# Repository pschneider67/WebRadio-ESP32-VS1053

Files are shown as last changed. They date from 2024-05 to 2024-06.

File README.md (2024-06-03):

Here I show the hardware of a small Internet radio consisting of: 
- ESP32 
- VS1053b 
- 2.2" TFT display
- Amplifier module PAM8403

The boards were created with KiCad version 8.

grafik

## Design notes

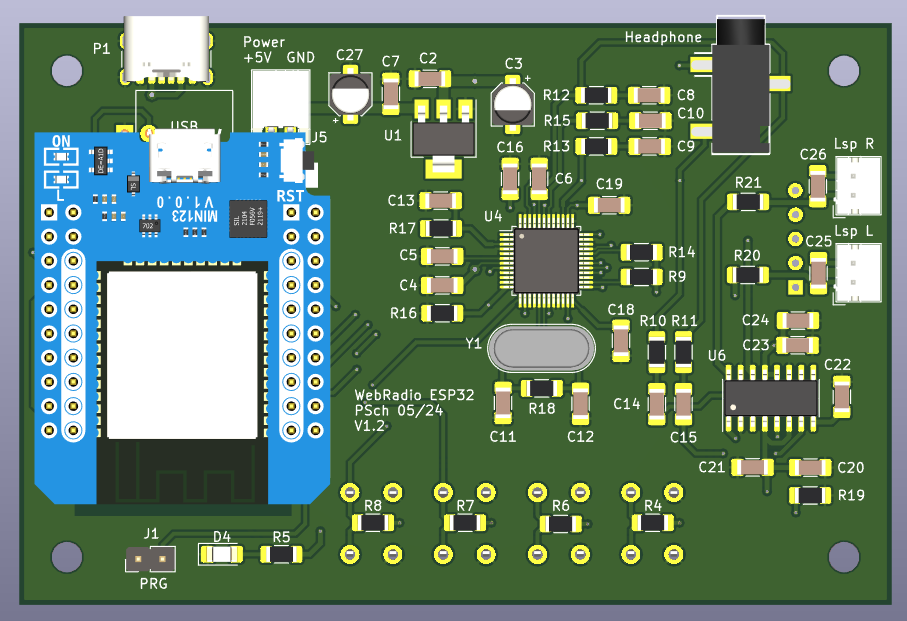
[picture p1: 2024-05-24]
WebRadio.png

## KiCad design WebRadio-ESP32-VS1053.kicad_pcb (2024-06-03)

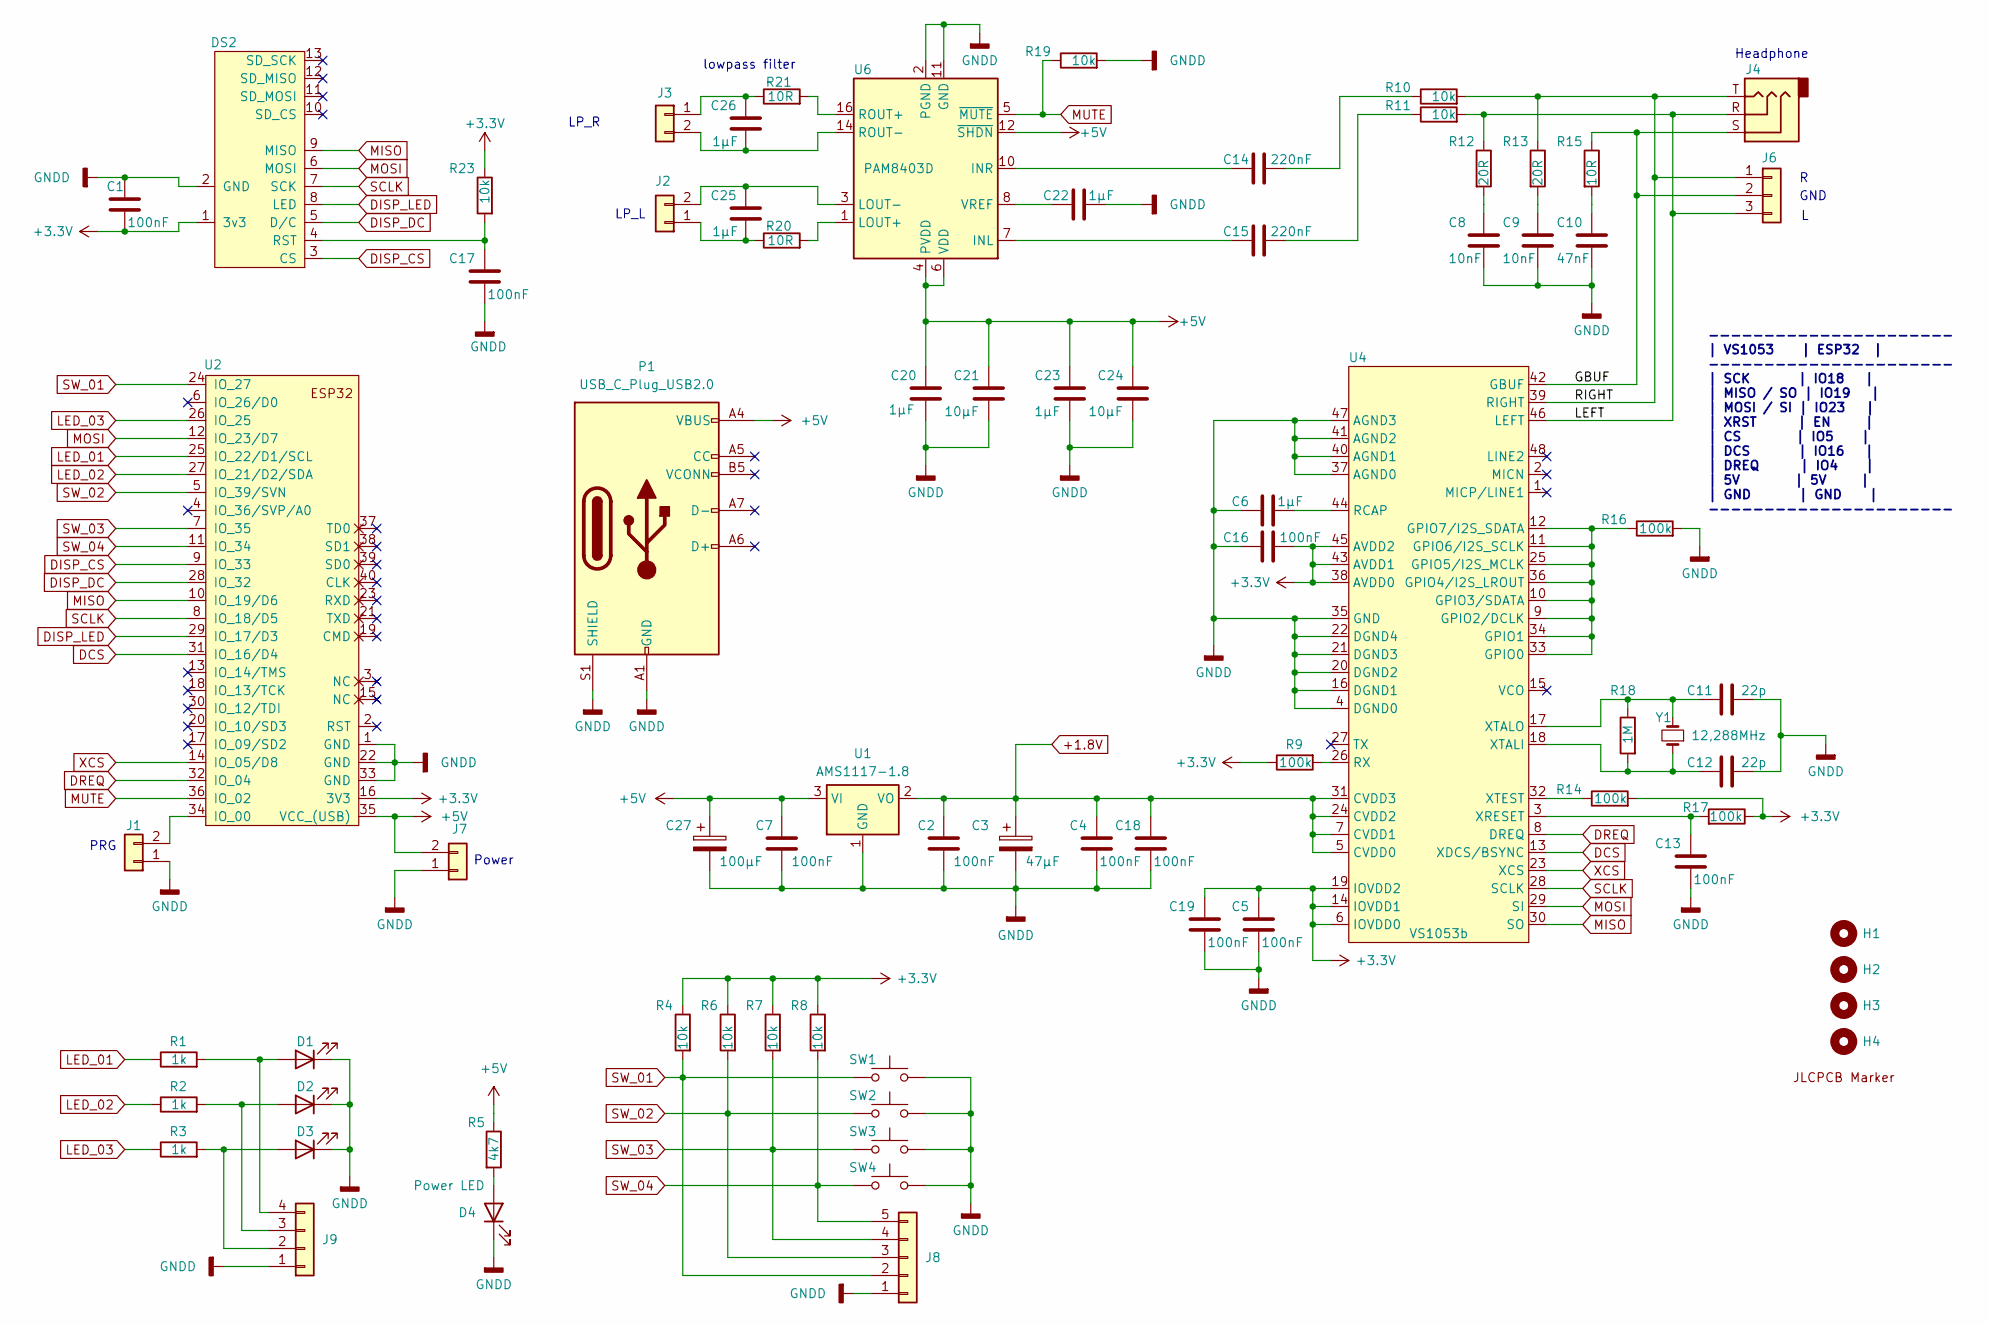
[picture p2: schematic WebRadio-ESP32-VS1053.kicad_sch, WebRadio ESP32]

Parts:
C1, C2, C4, C5, C7, C13, C16, C17, C18, C19: 100nF; C_1206_3216Metric_Pad1.33x1.80mm_HandSolder
C3: 47µF; CP_Elec_5x5.4
C6, C20, C22, C23, C25, C26: 1µF; C_1206_3216Metric_Pad1.33x1.80mm_HandSolder
C8, C9: 10nF; C_1206_3216Metric_Pad1.33x1.80mm_HandSolder
C10: 47nF; C_1206_3216Metric_Pad1.33x1.80mm_HandSolder
C11, C12: 22p; C_1206_3216Metric_Pad1.33x1.80mm_HandSolder
C14, C15: 220nF; C_1206_3216Metric_Pad1.33x1.80mm_HandSolder
C21, C24: 10µF; C_1206_3216Metric_Pad1.33x1.80mm_HandSolder
C27: 100µF; CP_Elec_5x5.4
D1, D2, D3: Power LED; LED_D3.0mm_SMD
D4: Power LED; LED_1206_3216Metric_Pad1.42x1.75mm_HandSolder
DS2: TFT2.2_SPI_4P_SD; TFT2.2_SPI_5P_SD
H1, H2, H3, H4: MountingHole; MountingHole_3.2mm_M3_ISO14580
J1: Conn_01x02; PinHeader_1x02_P2.54mm_Vertical
J2, J3, J7: JST PH 2mm; JST_PH_B2B-PH-K_1x02_P2.00mm_Vertical
J4: AudioJack3; Jack_3.5mm_SMT_Horizontal
J6: JST PH 2mm; JST_PH_B3B-PH-K_1x03_P2.00mm_Vertical
J8: Conn_01x05; JST_PH_B5B-PH-K_1x05_P2.00mm_Vertical
J9: Conn_01x04; JST_PH_B4B-PH-K_1x04_P2.00mm_Vertical
P1: USB_C_Plug_USB2.0; USB_C_Receptacle_GCT_USB4125-xx-x_6P_TopMnt_Horizontal
R1, R2, R3: 1k; R_1206_3216Metric_Pad1.30x1.75mm_HandSolder
R4, R6, R7, R8, R10, R11, R19, R23: 10k; R_1206_3216Metric_Pad1.30x1.75mm_HandSolder
R5: 4k7; R_1206_3216Metric_Pad1.30x1.75mm_HandSolder
R9, R14, R16, R17: 100k; R_1206_3216Metric_Pad1.30x1.75mm_HandSolder
R12, R13: 20R; R_1206_3216Metric_Pad1.30x1.75mm_HandSolder
R15, R20, R21: 10R; R_1206_3216Metric_Pad1.30x1.75mm_HandSolder
R18: 1M; R_1206_3216Metric_Pad1.30x1.75mm_HandSolder
SW1, SW2, SW3, SW4: SW_Push; SW_PUSH_6mm
U1: AMS1117-1.8; SOT-223
U2: mini_esp32; ESP32_mini
U4: VS1053b; LQFP-48_7x7mm_P0.5mm
U5: JLCPCB Marker; JLCPCB-Marker
U6: PAM8403D; SOP-16_3.9x9.9mm_P1.27mm
Y1: 12,288MHz; Crystal_HC49-U_Vertical

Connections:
+1.8V: C2.1, C3.1, C4.2, C18.2, U1.2 (VO), U4.5 (CVDD0), U4.7 (CVDD1), U4.24 (CVDD2), U4.31 (CVDD3)
+3.3V: C1.2, C5.2, C16.2, C19.2, DS2.1 (3v3), R4.1, R6.1, R7.1, R8.1, R9.1, R14.2, R17.1, R23.1, U2.16 (3V3), U4.6 (IOVDD0), U4.14 (IOVDD1), U4.19 (IOVDD2), U4.38 (AVDD0), U4.43 (AVDD1), U4.45 (AVDD2)
+5V: C7.1, C20.1, C21.1, C23.1, C24.1, C27.1, J7.2, P1.A4 (VBUS), P1.A9 (VBUS), P1.B4 (VBUS), P1.B9 (VBUS), R5.1, U1.3 (VI), U2.35 (VCC_(USB)), U6.4 (PVDD), U6.6 (VDD), U6.12 (~SHDN), U6.13 (PVDD)
/GBUF: J4.S, J6.2, R15.1, U4.42 (GBUF)
/LEFT: J4.R, J6.3, R11.2, R12.1, U4.46 (LEFT)
/RIGHT: J4.T, J6.1, R10.2, R13.1, U4.39 (RIGHT)
DCS: U2.31 (IO_16/D4), U4.13 (XDCS/BSYNC)
DISP_CS: DS2.3 (CS), U2.9 (IO_33)
DISP_DC: DS2.5 (D/C), U2.28 (IO_32)
DISP_LED: DS2.8 (LED), U2.29 (IO_17/D3)
DREQ: U2.32 (IO_04), U4.8 (DREQ)
GNDD: C1.1, C2.2, C3.2, C4.1, C5.1, C6.1, C7.2, C8.2, C9.2, C10.2, C11.1, C12.1, C13.1, C16.1, C17.2, C18.1, C19.1, C20.2, C21.2, C22.2, C23.2, C24.2, C27.2, D1.1 (K), D2.1 (K), D3.1 (K), D4.1 (K), DS2.2 (GND), J1.1, J7.1, J8.1, J9.1, P1.A1 (GND), P1.A12 (GND), P1.B1 (GND), P1.B12 (GND), P1.S1 (SHIELD), R16.2, R19.2, SW1.2, SW2.2, SW3.2, SW4.2, U1.1 (GND), U2.1 (GND), U2.22 (GND), U2.33 (GND), U4.4 (DGND0), U4.16 (DGND1), U4.20 (DGND2), U4.21 (DGND3), U4.22 (DGND4), U4.35 (GND), U4.37 (AGND0), U4.40 (AGND1), U4.41 (AGND2), U4.47 (AGND3), U6.2 (PGND), U6.11 (GND), U6.15 (PGND)
LED_01: R1.1, U2.25 (IO_22/D1/SCL)
LED_02: R2.1, U2.27 (IO_21/D2/SDA)
LED_03: R3.1, U2.26 (IO_25)
MISO: DS2.9 (MISO), U2.10 (IO_19/D6), U4.30 (SO)
MOSI: DS2.6 (MOSI), U2.12 (IO_23/D7), U4.29 (SI)
MUTE: R19.1, U2.36 (IO_02), U6.5 (~MUTE)
unnamed: C8.1, R12.2
unnamed: C9.1, R13.2
unnamed: C10.1, R15.2
unnamed: C14.2, R10.1
unnamed: C15.2, R11.1
unnamed: D1.2 (A), J9.4, R1.2
unnamed: D2.2 (A), J9.3, R2.2
unnamed: D3.2 (A), J9.2, R3.2
unnamed: D4.2 (A), R5.2
unnamed: C17.1, DS2.4 (RST), R23.2
unnamed: J1.2, U2.34 (IO_00)
unnamed: C25.2, J2.1, R20.1
unnamed: C25.1, J2.2, U6.3 (LOUT-)
unnamed: C26.1, J3.1, R21.1
unnamed: C26.2, J3.2, U6.14 (ROUT-)
unnamed: R16.1, U4.9 (GPIO2/DCLK), U4.10 (GPIO3/SDATA), U4.11 (GPIO6/I2S_SCLK), U4.12 (GPIO7/I2S_SDATA), U4.25 (GPIO5/I2S_MCLK), U4.33 (GPIO0), U4.34 (GPIO1), U4.36 (GPIO4/I2S_LROUT)
unnamed: C6.2, U4.44 (RCAP)
unnamed: R9.2, U4.26 (RX)
unnamed: C13.2, R17.2, U4.3 (XRESET)
unnamed: C12.2, R18.2, U4.18 (XTALI), Y1.1
unnamed: C11.2, R18.1, U4.17 (XTALO), Y1.2
unnamed: R14.1, U4.32 (XTEST)
unnamed: C15.1, U6.7 (INL)
unnamed: C14.1, U6.10 (INR)
unnamed: R20.2, U6.1 (LOUT+)
unnamed: R21.2, U6.16 (ROUT+)
unnamed: C22.1, U6.8 (VREF)
SCLK: DS2.7 (SCK), U2.8 (IO_18/D5), U4.28 (SCLK)
SW_01: J8.2, R4.2, SW1.1, U2.24 (IO_27)
SW_02: J8.3, R6.2, SW2.1, U2.5 (IO_39/SVN)
SW_03: J8.4, R7.2, SW3.1, U2.7 (IO_35)
SW_04: J8.5, R8.2, SW4.1, U2.11 (IO_34)
XCS: U2.14 (IO_05/D8), U4.23 (XCS)

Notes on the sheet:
PRG
LP_L
LP_R
Power
GND
---------------------- | VS1053 | ESP32 | ---------------------- | SCK | IO18 | | MISO / SO | IO19 | | MOSI / SI | IO23 | | XRST | EN | | CS | IO5 | | DCS | IO16 | | DREQ | IO4 | | 5V | 5V | | GND | GND | ----------------------
Headphone
lowpass filter

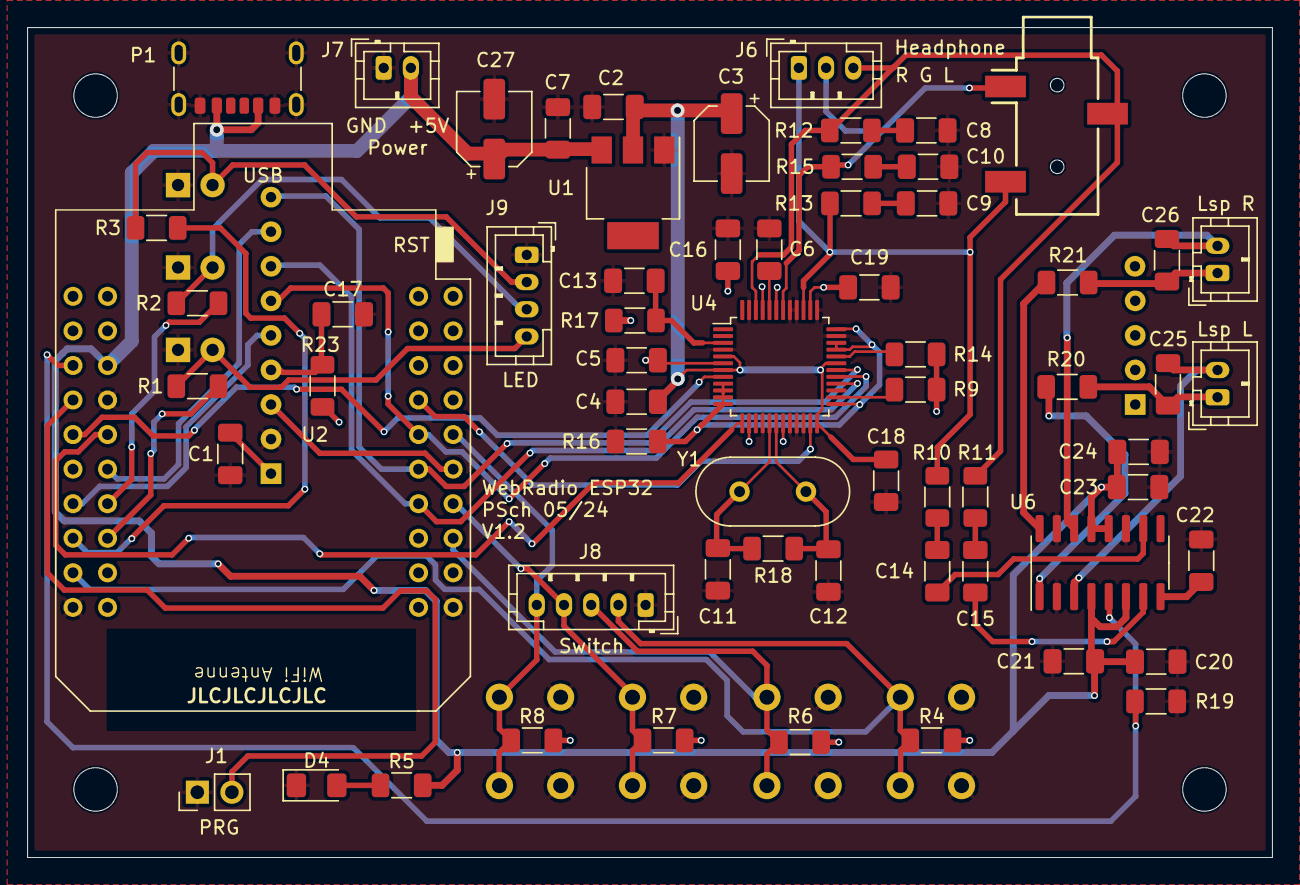
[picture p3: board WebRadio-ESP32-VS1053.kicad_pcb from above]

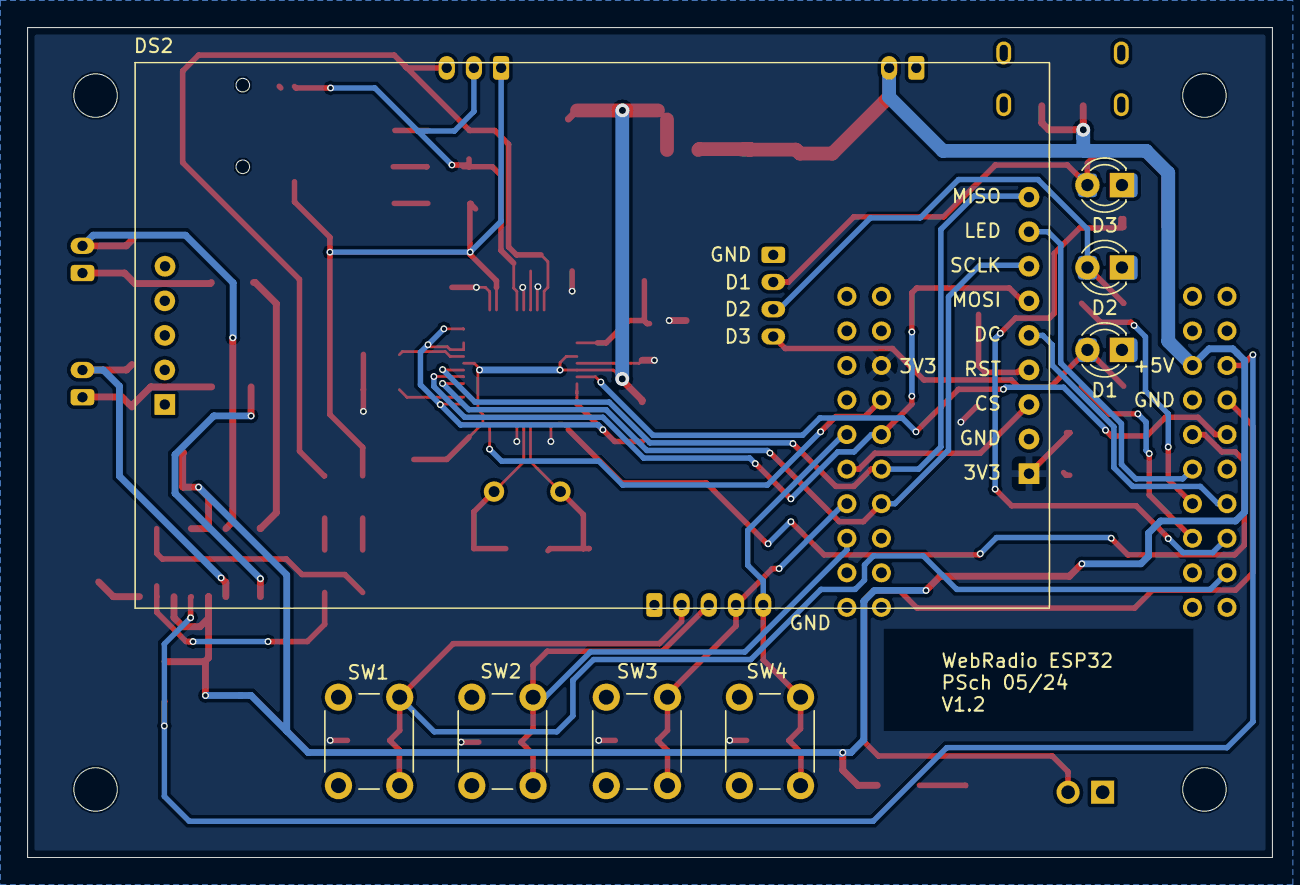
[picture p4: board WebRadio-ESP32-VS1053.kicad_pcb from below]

Board: 2 copper layers, 91.5 x 61.0 mm, 77 parts (8 on the bottom side), 51 nets.

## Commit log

2024-05-20 first commit
    KiCad data of a small internet radio with ESP32 and VS1053 decoder chip.
    [WebRadio-ESP32-VS1053.kicad_pcb, WebRadio-ESP32-VS1053.kicad_sch]
2024-05-24 include power over usb-c and jst connector
    [WebRadio-ESP32-VS1053.kicad_pcb, WebRadio-ESP32-VS1053.kicad_sch]
2024-05-24 change some comments
    [WebRadio-ESP32-VS1053.kicad_pcb, WebRadio-ESP32-VS1053.kicad_sch]
2024-05-25 add new footrint for 3mm LED to us also SMD LED's
    [WebRadio-ESP32-VS1053.kicad_pcb, WebRadio-ESP32-VS1053.kicad_sch]
2024-05-26 add audio output connector
    [WebRadio-ESP32-VS1053.kicad_pcb, WebRadio-ESP32-VS1053.kicad_sch]
2024-05-26 add labeling
    [WebRadio-ESP32-VS1053.kicad_pcb]
2024-05-26 change date of drawing
    [WebRadio-ESP32-VS1053.kicad_sch]
2024-05-27 add pin header for leds and swiches
    [WebRadio-ESP32-VS1053.kicad_pcb, WebRadio-ESP32-VS1053.kicad_sch]
2024-05-30 include JST PH connectors
    [WebRadio-ESP32-VS1053.kicad_pcb, WebRadio-ESP32-VS1053.kicad_sch]
2024-06-03 change some silkscreen data
    [WebRadio-ESP32-VS1053.kicad_pcb, WebRadio-ESP32-VS1053.kicad_sch]
